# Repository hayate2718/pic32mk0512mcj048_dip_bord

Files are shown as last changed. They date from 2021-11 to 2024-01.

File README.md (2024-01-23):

# pic32mk0512mcj048_dip_bord
## 仕様
1. PIC32MK0512MCJ048のDIP化基板
2. 振動子などの最低限必要な外部回路を搭載する
3. 書き込み端子以外の汎用IOをすべて使用可にする
4. CANトランシーバ搭載、LED搭載
5. メインオシレータ16MHz
6. セカンダリオシレータ32.768KHz

ReservedPin

|Number|Name|Function|
|---|---|---|
|4|MCLR|MCLR|
|5|VSS|VSS|
|6|VDD|VDD|
|11|RB0|**VREF-**|
|12|RB1|**VREF+**|
|15|AVDD|AVDD|
|16|AVSS|AVSS|
|21|VSS|VSS|
|22|VDD|VDD|
|25|RA4|**C1RX**|
|26|VDD|VDD|
|27|RC12|**OSCI**|
|28|RC15|**OSCO**|
|29|VSS|VSS|
|30|RD8|**LED_R**|
|31|RB5|**PGD2**|
|32|RB6|**PGC2**|
|33|RC10|**LED_G**|
|34|RB7|**C1TX**|
|35|RC13|**SOSCI**|
|36|RB8|**SOSCO**|
|42|VSS|VSS|
|43|VDD|VDD|

pic32mcj048_top

## エラッタ
Harmony V3 でコードを出力して、PLIBを使ったときに出力されたコードを書き換えないとうまく動作しないことがあった。<br>
その対処を記録しておく。

### コンパイラの最適化
割り込みハンドラと共有する変数に`volatile`修飾子をつける。

### SPI slave
受信割り込みハンドラ内でSPIxBUFが一回目の読み取り以降変化しない。<br>
対処:SPIxBUFに書き込みを行いSPIxBUFをクリアする。<br>
以下例
```c++
void SPI2_RX_InterruptHandler (void)
{
    uint32_t receivedData = 0;

    spi2Obj.rxInterruptActive = true;

    while (!(SPI2STAT & _SPI2STAT_SPIRBE_MASK))
    {
        /* Receive buffer is not empty. Read the received data. */
        receivedData = SPI2BUF;
        
        memset((void*)&SPI2BUF,0,sizeof(SPI2BUF)); //add code

        if (spi2Obj.rdInIndex < SPI2_READ_BUFFER_SIZE)
        {
            SPI2_ReadBuffer[spi2Obj.rdInIndex++] = receivedData;
        }
    }

    /* Clear the receive interrupt flag */
    SPI2_CLEAR_RX_INT_FLAG();

    spi2Obj.rxInterruptActive = false;

    /* Check if CS interrupt occured before the RX interrupt and that CS interrupt delegated the responsibility to give
     * application callback to the RX interrupt */

    if (spi2Obj.csInterruptPending == true)
    {
        spi2Obj.csInterruptPending = false;
        spi2Obj.transferIsBusy = false;

        spi2Obj.wrOutIndex = 0;
        spi2Obj.nWrBytes = 0;

        if(spi2Obj.callback != NULL)
        {
            spi2Obj.callback(spi2Obj.context);
        }

        /* Clear the read index. Application must read out the data by calling SPI2_Read API in the callback */
        spi2Obj.rdInIndex = 0;
    }
}
```
## 考え中
<b>
PINネームを大きめに入れたい<br>
LED駆動用FETをプルダウンする<br>
IO引き出し線をもう少し太くしたい<br>
在庫があればCANトラをSOICにしたい<br>
redemi が長くなりすぎたらwikiにまとめる。
</b>

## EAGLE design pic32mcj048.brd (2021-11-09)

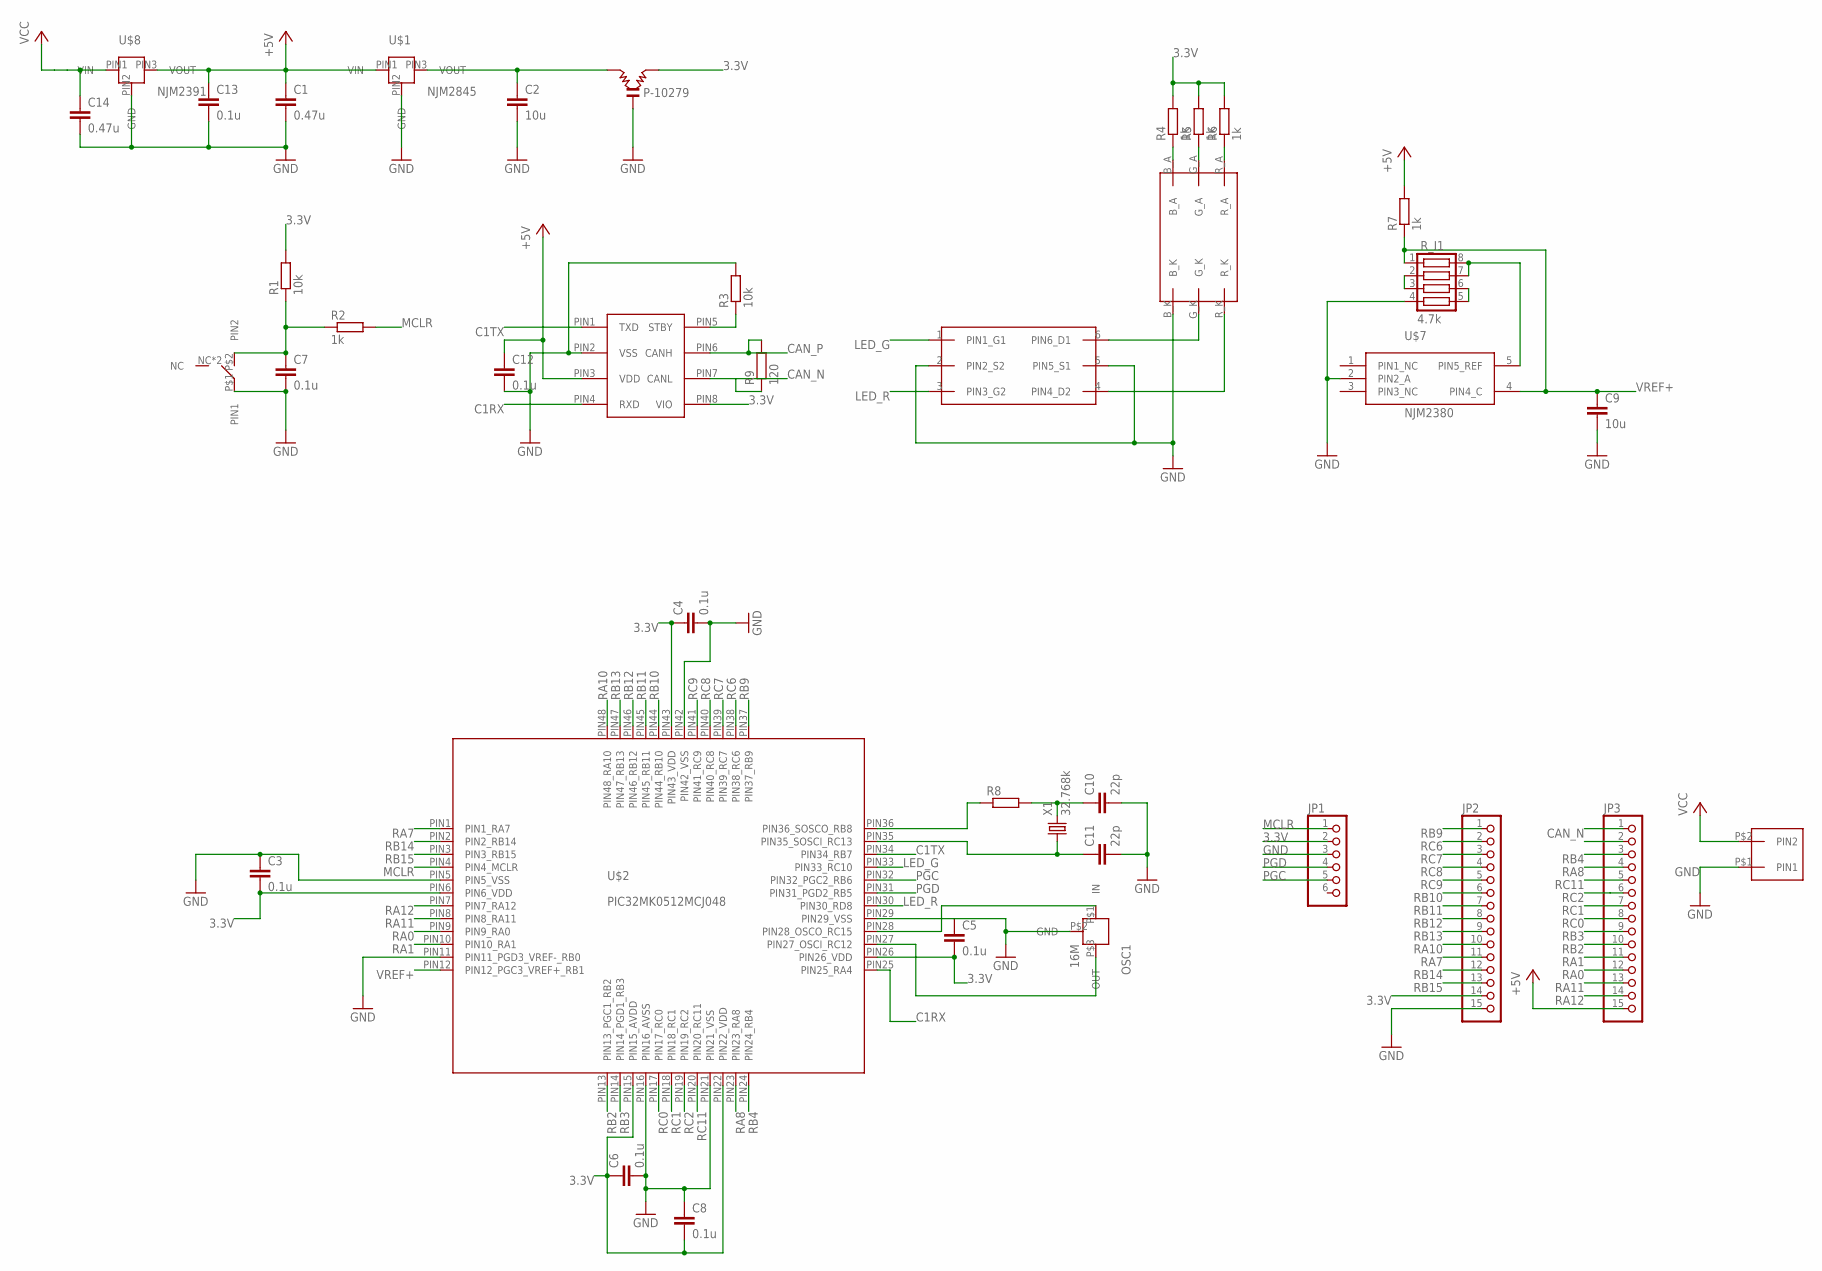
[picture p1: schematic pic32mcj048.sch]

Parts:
C1, C14: 0.47u; C1608
C2, C9: 10u; C1608
C3, C4, C5, C6, C7, C8, C12, C13: 0.1u; C1608
C10, C11: 22p; C1608
IC1: MCP2562; DIL8
JP1: PINHD-1X6; 1X06
JP2, JP3: PINHD-1X15; 1X15
OSC1: 16M; CSTNE#
P-10279: LCL
R1, R3: 10k; 1608
R2, R4, R5, R6, R7: 1k; 1608
R8: R_REG; 1608
R9: 120; 1608
R_I1: 4.7k; 1005X4RESISTOR
U$1: NJM2845; TO252
U$2: PIC32MK0512MCJ048; LQFP48PIN
U$3: TAKUTOSUITTI2
U$4: XH_2P
U$5: RGB_LED
U$6: FDC6305; SSOT6
U$7: NJM2380; SOT23-5
U$8: NJM2391; TO252
X1: 32.768k; FC255

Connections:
3.3V: C3.2, C4.1, C5.2, C6.1, C8.2, IC1.PIN8 (VIO), JP1.2, JP2.14, P-10279.2, R1.2, R4.2, R5.2, R6.2, U$2.PIN6 (PIN6_VDD), U$2.PIN15 (PIN15_AVDD), U$2.PIN22 (PIN22_VDD), U$2.PIN26 (PIN26_VDD), U$2.PIN43 (PIN43_VDD)
+5V: C1.1, C12.1, C13.1, IC1.PIN3 (VDD), JP3.15, R7.2, U$1.PIN1 (VIN), U$8.PIN3 (VOUT)
C1RX: IC1.PIN4 (RXD), U$2.PIN25 (PIN25_RA4)
C1TX: IC1.PIN1 (TXD), U$2.PIN34 (PIN34_RB7)
CAN_N: IC1.PIN7 (CANL), JP3.1, R9.1
CAN_P: IC1.PIN6 (CANH), JP3.2, R9.2
GND: C1.2, C2.2, C3.1, C4.2, C5.1, C6.2, C7.2, C8.1, C9.2, C10.2, C11.2, C12.2, C13.2, C14.2, IC1.PIN2 (VSS), JP1.3, JP2.15, OSC1.P$2 (GND), P-10279.0 (GND), R3.2, R_I1.4, U$1.PIN2 (GND), U$2.PIN5 (PIN5_VSS), U$2.PIN11 (PIN11_PGD3_VREF-_RB0), U$2.PIN16 (PIN16_AVSS), U$2.PIN21 (PIN21_VSS), U$2.PIN29 (PIN29_VSS), U$2.PIN42 (PIN42_VSS), U$3.P$1 (PIN1), U$4.P$1 (PIN1), U$5.B_K, U$6.2 (PIN2_S2), U$6.5 (PIN5_S1), U$7.2 (PIN2_A), U$8.PIN2 (GND)
LED_G: U$2.PIN33 (PIN33_RC10), U$6.1 (PIN1_G1)
LED_R: U$2.PIN30 (PIN30_RD8), U$6.3 (PIN3_G2)
MCLR: JP1.1, R2.2, U$2.PIN4 (PIN4_MCLR)
unnamed: C2.1, P-10279.1, U$1.PIN3 (VOUT)
unnamed: C7.1, R1.1, R2.1, U$3.P$2 (PIN2)
unnamed: OSC1.P$1 (IN), U$2.PIN28 (PIN28_OSCO_RC15)
unnamed: OSC1.P$3 (OUT), U$2.PIN27 (PIN27_OSCI_RC12)
unnamed: IC1.PIN5 (STBY), R3.1
unnamed: C10.1, R8.2, X1.P$2 (2)
unnamed: C11.1, U$2.PIN35 (PIN35_SOSCI_RC13), X1.P$1 (1)
unnamed: U$5.G_K, U$6.6 (PIN6_D1)
unnamed: U$5.R_K, U$6.4 (PIN4_D2)
unnamed: R8.1, U$2.PIN36 (PIN36_SOSCO_RB8)
unnamed: R4.1, U$5.B_A
unnamed: R5.1, U$5.G_A
unnamed: R6.1, U$5.R_A
unnamed: R_I1.7, R_I1.8, U$7.5 (PIN5_REF)
unnamed: R_I1.2, R_I1.3
unnamed: R_I1.5, R_I1.6
PGC: JP1.5, U$2.PIN32 (PIN32_PGC2_RB6)
PGD: JP1.4, U$2.PIN31 (PIN31_PGD2_RB5)
RA0: JP3.12, U$2.PIN9 (PIN9_RA0)
RA1: JP3.11, U$2.PIN10 (PIN10_RA1)
RA7: JP2.11, U$2.PIN1 (PIN1_RA7)
RA8: JP3.4, U$2.PIN23 (PIN23_RA8)
RA10: JP2.10, U$2.PIN48 (PIN48_RA10)
RA11: JP3.13, U$2.PIN8 (PIN8_RA11)
RA12: JP3.14, U$2.PIN7 (PIN7_RA12)
RB2: JP3.10, U$2.PIN13 (PIN13_PGC1_RB2)
RB3: JP3.9, U$2.PIN14 (PIN14_PGD1_RB3)
RB4: JP3.3, U$2.PIN24 (PIN24_RB4)
RB9: JP2.1, U$2.PIN37 (PIN37_RB9)
RB10: JP2.6, U$2.PIN44 (PIN44_RB10)
RB11: JP2.7, U$2.PIN45 (PIN45_RB11)
RB12: JP2.8, U$2.PIN46 (PIN46_RB12)
RB13: JP2.9, U$2.PIN47 (PIN47_RB13)
RB14: JP2.12, U$2.PIN2 (PIN2_RB14)
RB15: JP2.13, U$2.PIN3 (PIN3_RB15)
RC0: JP3.8, U$2.PIN17 (PIN17_RC0)
RC1: JP3.7, U$2.PIN18 (PIN18_RC1)
RC2: JP3.6, U$2.PIN19 (PIN19_RC2)
RC6: JP2.2, U$2.PIN38 (PIN38_RC6)
RC7: JP2.3, U$2.PIN39 (PIN39_RC7)
RC8: JP2.4, U$2.PIN40 (PIN40_RC8)
RC9: JP2.5, U$2.PIN41 (PIN41_RC9)
RC11: JP3.5, U$2.PIN20 (PIN20_RC11)
VCC: C14.1, U$4.P$2 (PIN2), U$8.PIN1 (VIN)
VREF+: C9.1, R7.1, R_I1.1, U$2.PIN12 (PIN12_PGC3_VREF+_RB1), U$7.4 (PIN4_C)

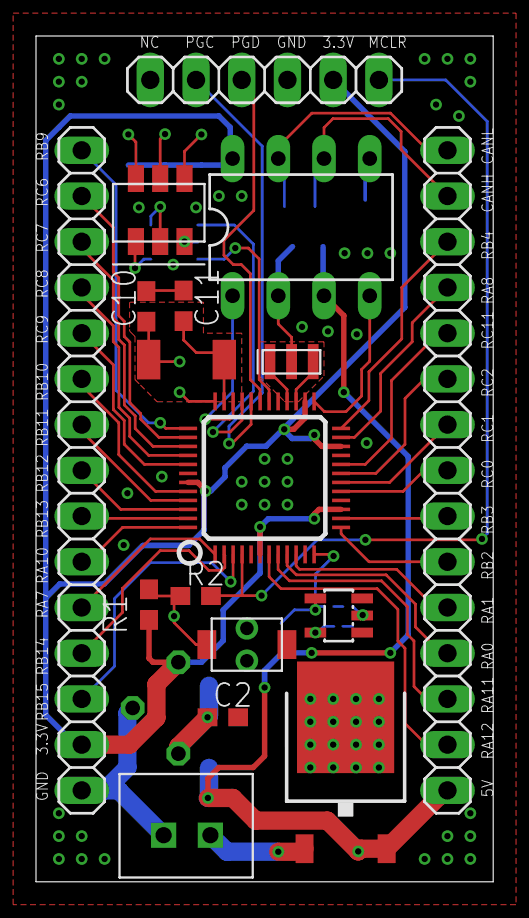
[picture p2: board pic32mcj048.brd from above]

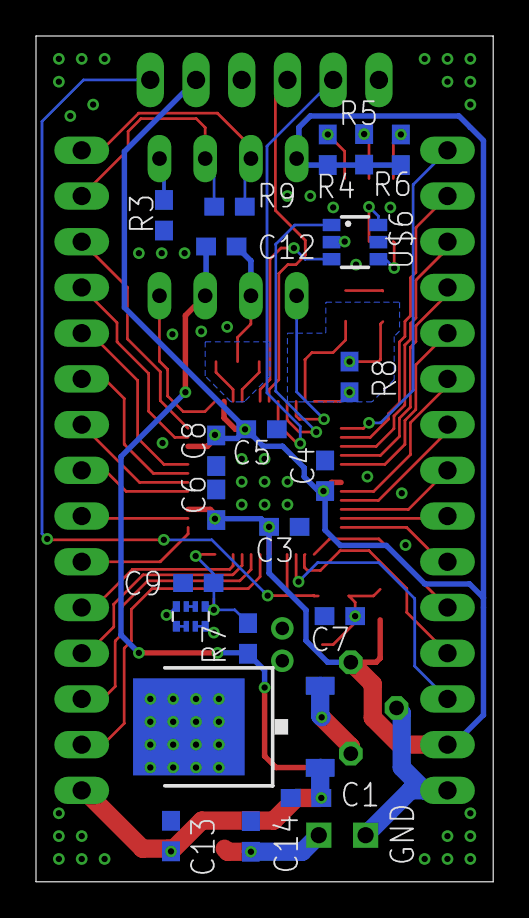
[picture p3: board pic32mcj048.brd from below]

Board: 2 copper layers, 25.4 x 47.0 mm, 39 parts (21 on the bottom side), 55 nets.

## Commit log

2021-02-25 ファイル作成
    [pic32mcj048.brd, pic32mcj048.sch]
2021-02-25 ignoreのついか
2021-02-25 リセット回路、書き込み回路を作った
    [pic32mcj048.brd, pic32mcj048.sch]
2021-07-27 brdfileを編集
    [pic32mcj048.brd, pic32mcj048.sch]
2021-08-13 sch完成
    [pic32mcj048.brd, pic32mcj048.sch]
2021-09-24 基本設計完了、あとは調整など
    [pic32mcj048.brd, pic32mcj048.sch]
2021-09-28 完成、ガーバーデータ追加
    [pic32mcj048.brd]
2021-11-09 mcp2562スタンバイピンプルダウン
    [pic32mcj048.brd, pic32mcj048.sch]
